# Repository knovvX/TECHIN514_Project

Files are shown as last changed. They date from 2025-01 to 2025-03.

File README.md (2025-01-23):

# TECHIN514_Project

`Diyun Lu 2430741`

### Sonic Flow - A Music Visualization Device

#### Overview

Sonic Flow senses the music around and visualize the waveform. The sensing device is responsible for detecting the music around. And the display device will display the corresponding waveforms together with a part acting as a monotrome to display the bpm.

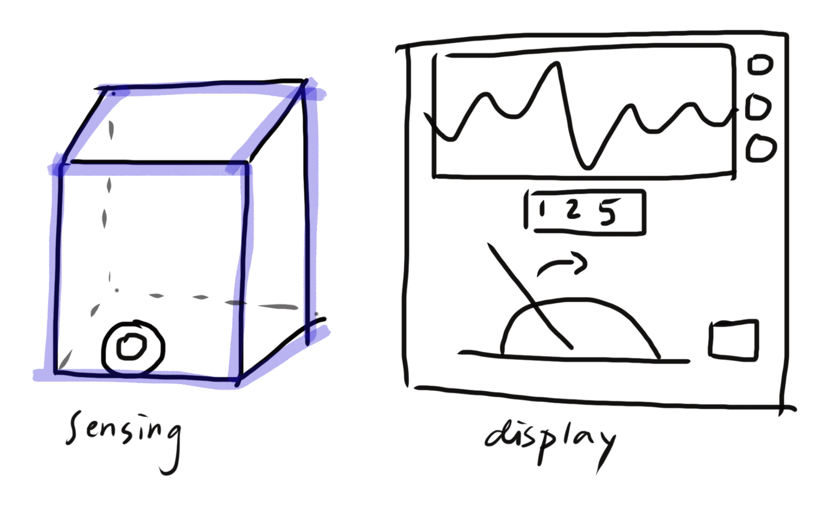
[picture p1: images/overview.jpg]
 

#### Sensing Device

The sensing device is equipped with a microphone sensor, which is recording the sound waves and send it to display device. A bluetooth module of esp32 will handle this transmission, since in the application, these two devices should not be very far, so I chose bluetooth. Also the sound level will affect the brightness of the LED strip around the cube, louder the sound is, brighter the LED is.

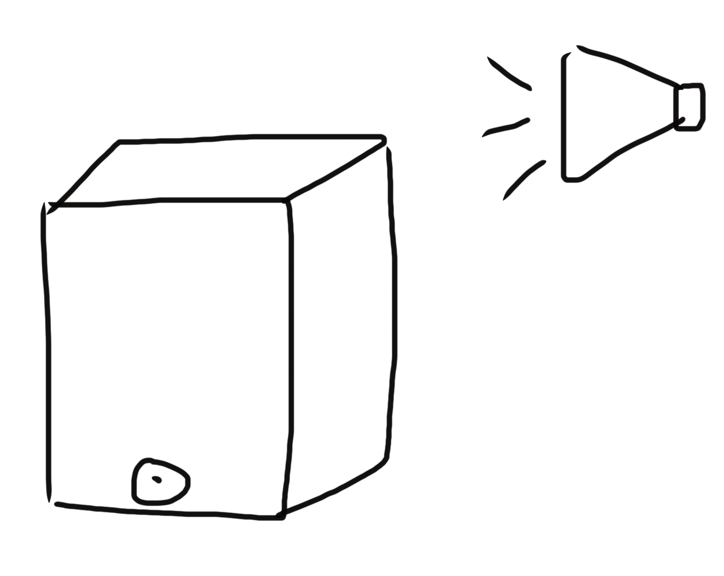
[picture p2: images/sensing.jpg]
sensing


#### Display Device

The display device is mainly displaying the waveform and the bpm of the music detected. BPM is displayed through the stepper-motor-driven gauge needle as a monotrome. Further ML will be embedded on the microncontroller to detect the emotion of the music and also display it on the OLED. A design of different kinds of waveforms will be enabled by a button to switch between different designs.

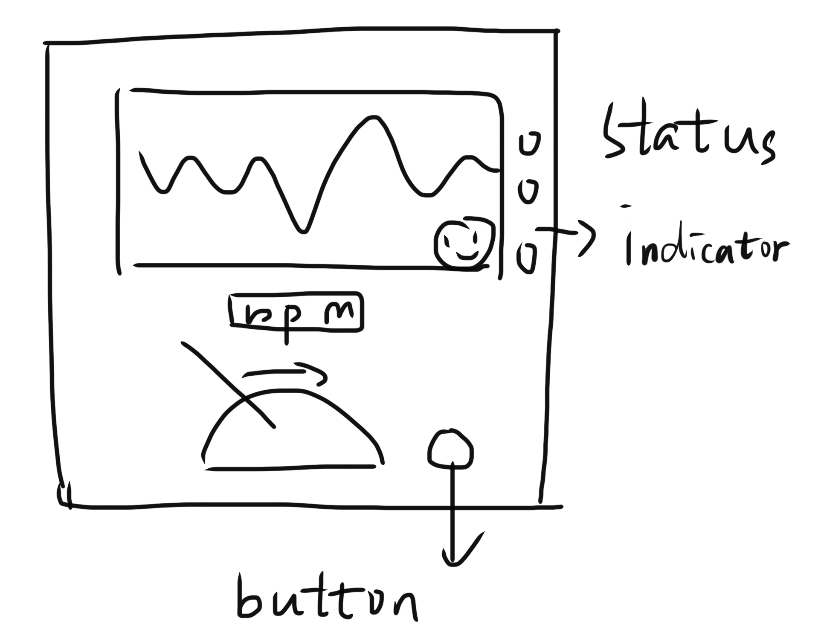
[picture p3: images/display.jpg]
display


#### Connection Diagram

The connection of the two parts are shown below. They connect with each other through ESP32's Bluetooth module. And ESP32 is responsible for the control of other sensors.

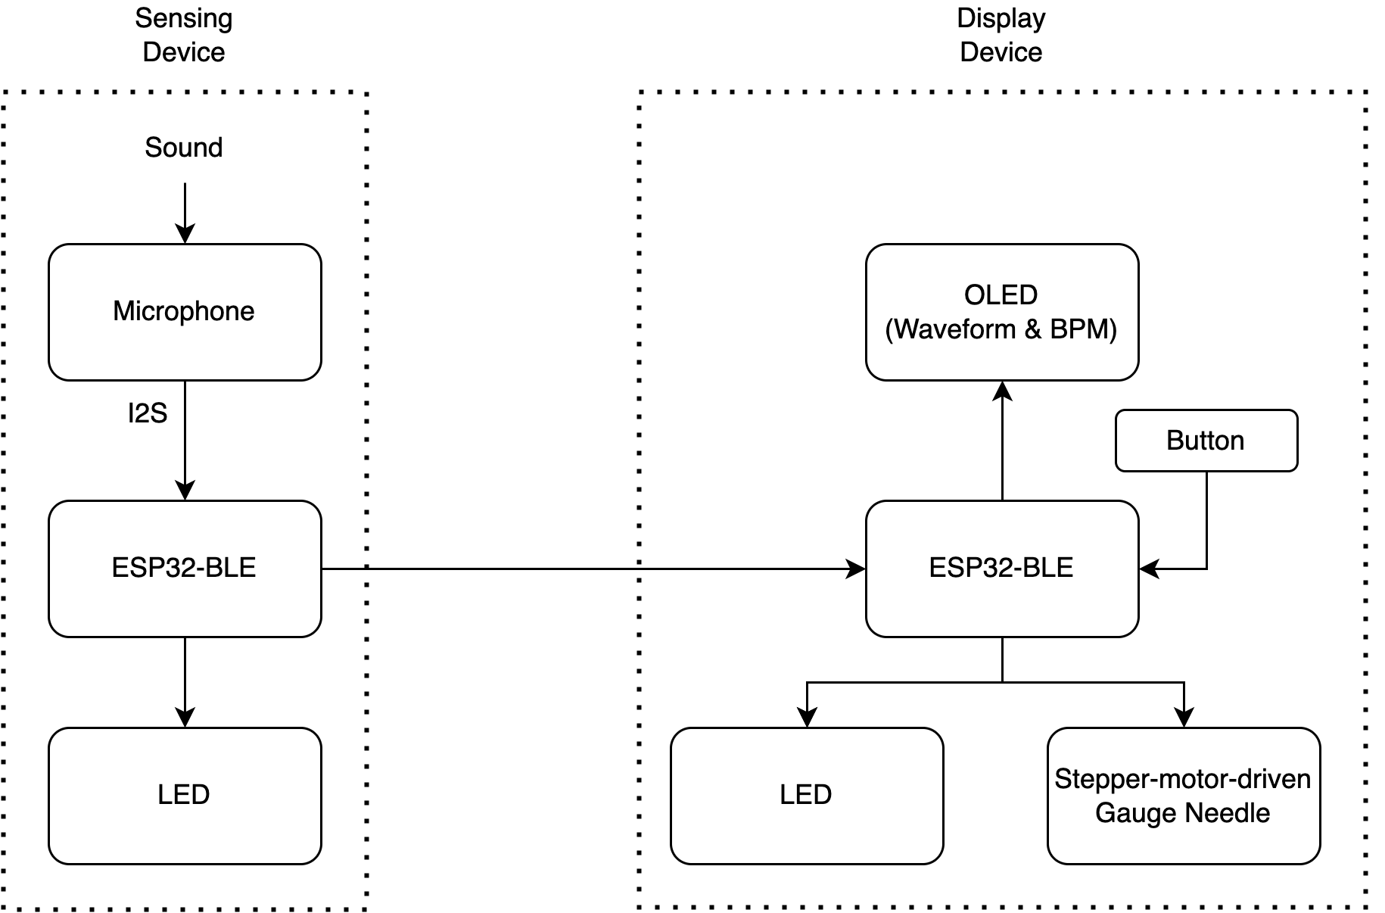
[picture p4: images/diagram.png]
diagram


#### Device Composition

| Device | Sensor / Element | Functionality |
| --- | --- | --- |
| Sensing | SPH0645LM4H-B | Microphone |
| Sensing | 3.7V / ++? | Battery |
| Display | 3.7V / ++? | Battery |
| Display | SSD1305(Long, for waves),https://www.adafruit.com/product/292,Adafruit OLED FeatherWing(Small, for displaying bpm) | OLED |
| Display | D6R90 F2 LFS | Button |
| Display/Sensing | RGB | LED |
| Display | https://www.adafruit.com/product/2424 | Stepper-motor-driven Gauge Needle |
| | ESP32 | Bluetooth and control |

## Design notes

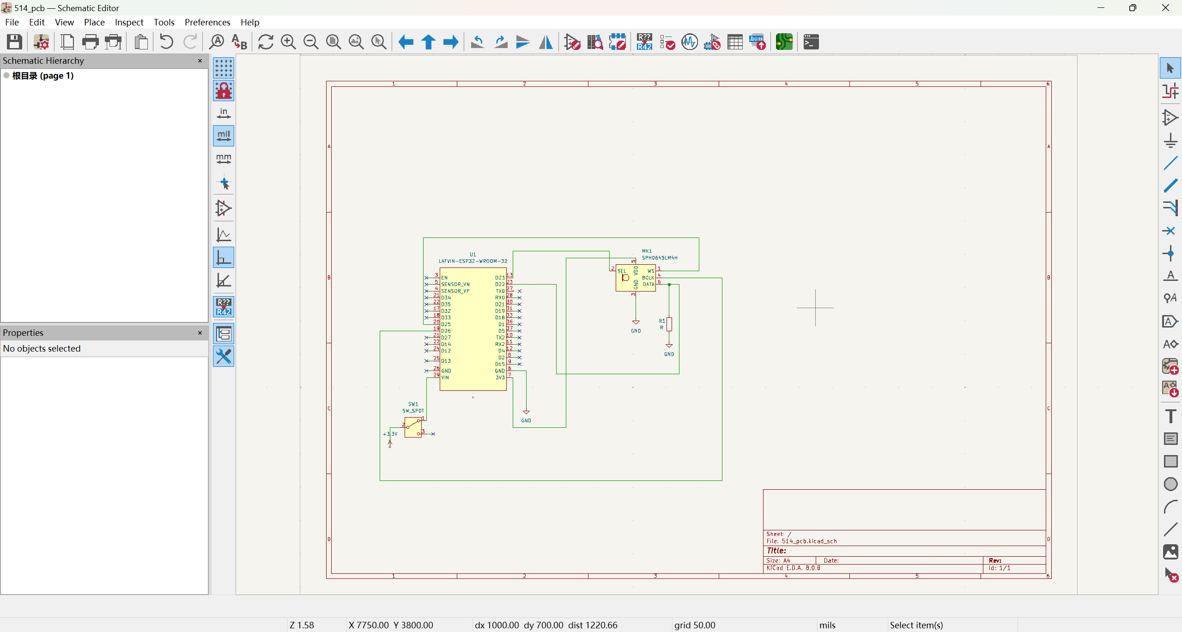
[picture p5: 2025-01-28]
pcb_schematic.png

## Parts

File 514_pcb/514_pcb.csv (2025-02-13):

Source: | /Users/diyunlu/Documents/GitHub/TECHIN514_Project/514_pcb/514_pcb.kicad_sch
Date: | 2025-02-12T16:00:10-0800
Tool: | Eeschema 8.0.8
Generator: | /Applications/KiCad/KiCad.app/Contents/SharedSupport/plugins/bom_csv_grouped_by_value.py
Component Count: | 5
Collated Components:
Item | Qty | Reference(s) | Value | LibPart | Footprint | Datasheet | DNP | Datasheet | Description | Footprint
1 | 1 | BT1 | Battery_Cell | Device:Battery_Cell | Connector_JST:JST_NV_B02P-NV_1x02_P5.00mm_Vertical | ~ |  | ~ | Single-cell battery | Connector_JST:JST_NV_B02P-NV_1x02_P5.00mm_Vertical
2 | 1 | MK1 | SPH0645LM4H | Sensor_Audio:SPH0645LM4H | Sensor_Audio:Knowles_SPH0645LM4H-6_3.5x2.65mm | https://www.knowles.com/docs/default-source/default-document-library/sph0645lm4h-1-datasheet.pdf |  | https://www.knowles.com/docs/default-source/default-document-library/sph0645lm4h-1-datasheet.pdf | Knowles MEMS Microphone, 24-bit I2S, 65 dBA SNR, LGA-6 | Sensor_Audio:Knowles_SPH0645LM4H-6_3.5x2.65mm
3 | 1 | R1 | R = 10k | Device:R | Resistor_SMD:R_0603_1608Metric_Pad0.98x0.95mm_HandSolder | ~ |  | ~ | Resistor | Resistor_SMD:R_0603_1608Metric_Pad0.98x0.95mm_HandSolder
4 | 1 | SW1 | SW_SPDT | Switch:SW_SPDT | Button_Switch_SMD:SW_SPDT_PCM12 | ~ |  | ~ | Switch, single pole double throw | Button_Switch_SMD:SW_SPDT_PCM12
5 | 1 | U1 | ~ | SeeedXiao:XIAO_ESP32_SENSE | SeeedXiao:XIAO_ESP32_SENSE |  |  |  |  | SeeedXiao:XIAO_ESP32_SENSE

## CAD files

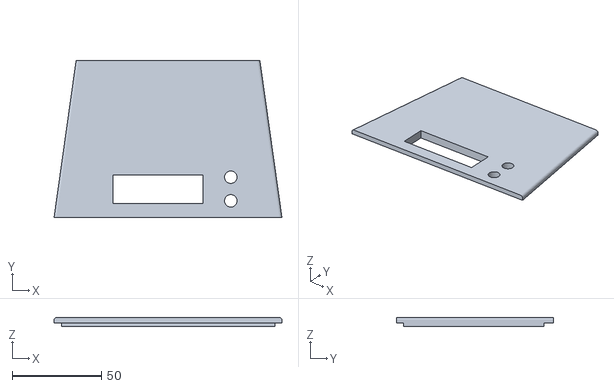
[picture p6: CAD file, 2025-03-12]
514_display/test 3d print/514_display v7upbpt.stl
128.0 x 88.4 x 5.02

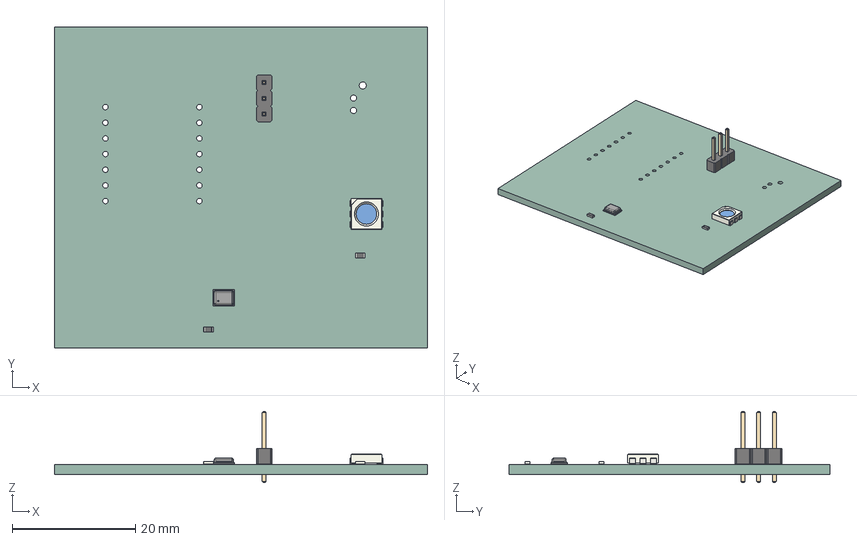
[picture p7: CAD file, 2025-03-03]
514_pcb/514_pcb.step
60.5 x 52.0 x 11.5 mm
R_0603_1608Metric x 2
PinHeader_1x03_P254mm_Vertical
LED_RGB_5050_6
Knowles_SPH0645LM4H-6_3.5x2.65mm
514_pcb_PCB

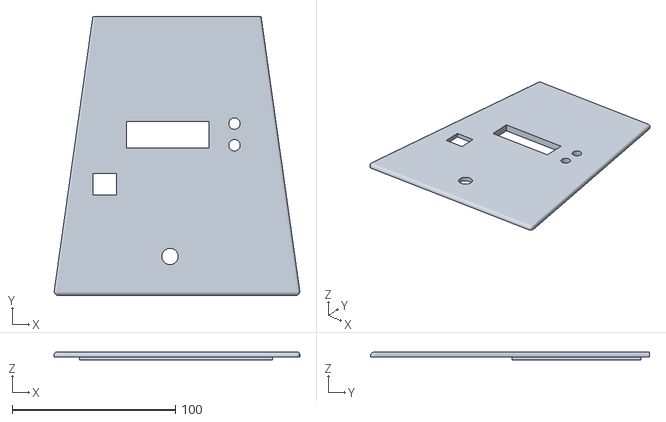
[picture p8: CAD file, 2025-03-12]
514_display/514_display v9lid.stl
150.5 x 170.9 x 5.05

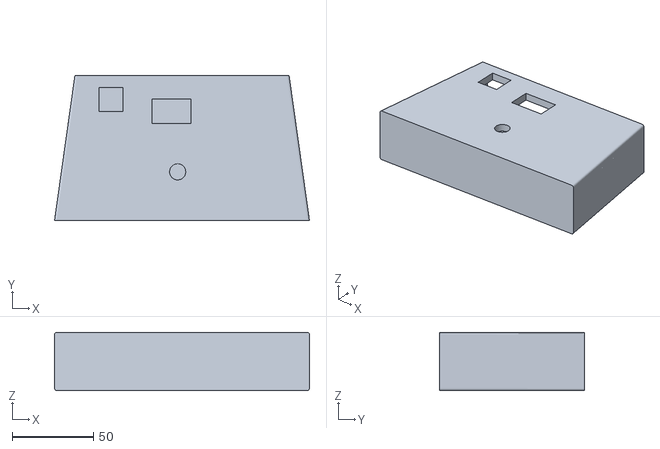
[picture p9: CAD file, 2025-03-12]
514_display/test 3d print/514_display v2botbig.stl
157.4 x 89.6 x 36.1

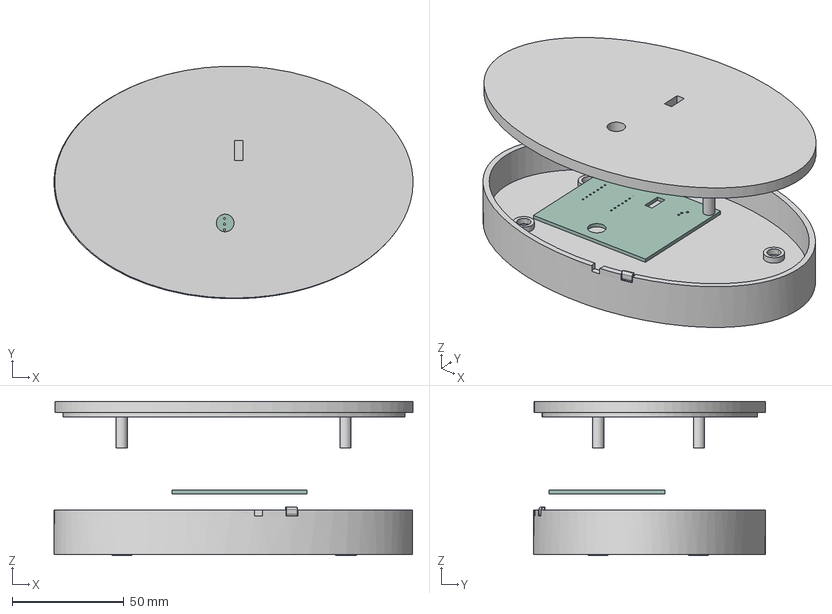
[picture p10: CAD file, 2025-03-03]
514_pcb/514_pcb_sensing_enclosure v12.step
160.5 x 103.9 x 69.1 mm
514_pcb_PCB

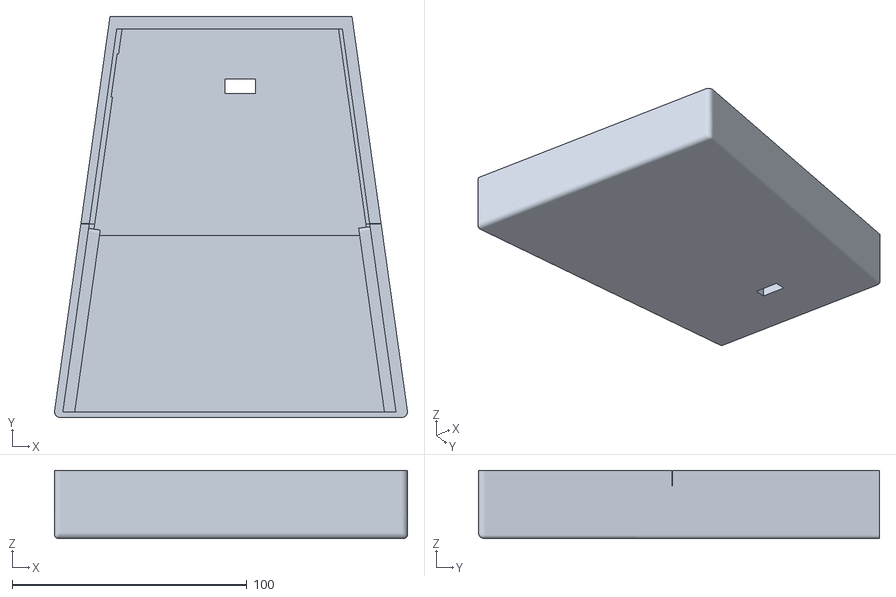
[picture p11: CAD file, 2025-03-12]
514_display/514_display v9.stl
150.4 x 171.0 x 29.0

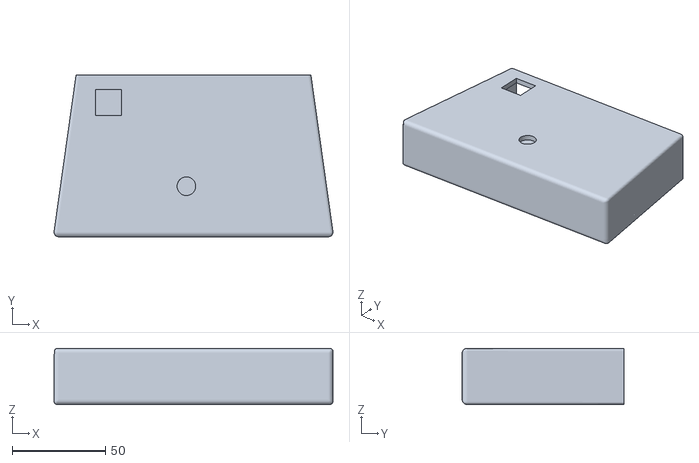
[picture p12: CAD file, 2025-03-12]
514_display/test 3d print/514_display v3_bot.stl
149.5 x 86.6 x 30.1

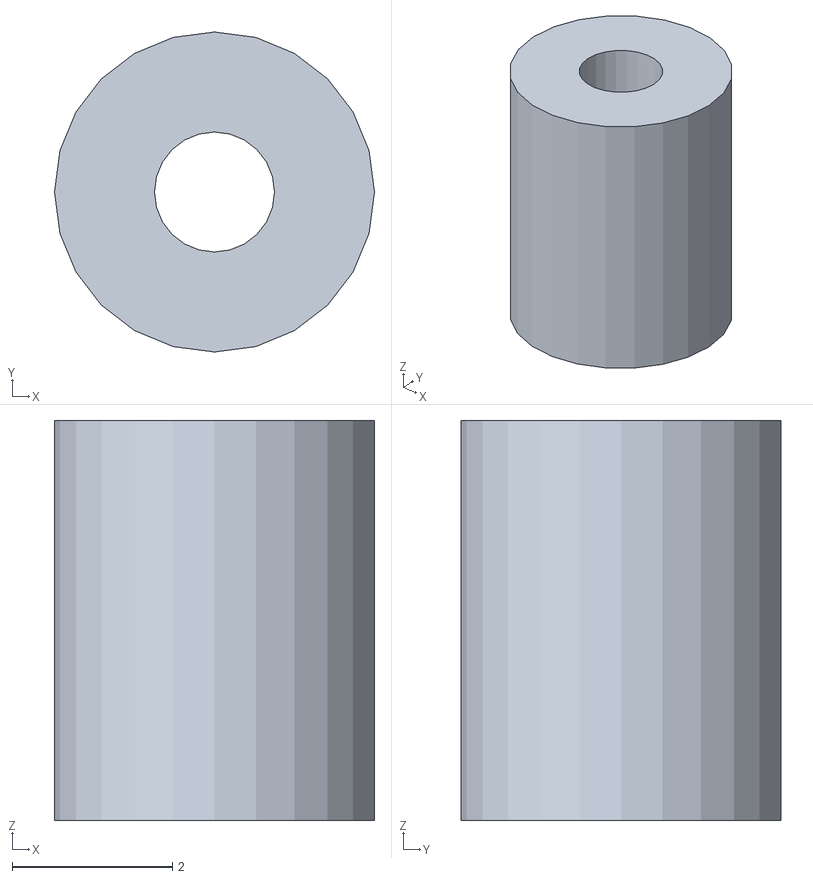
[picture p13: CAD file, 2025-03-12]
514_display/needle bot.stl
4.00 x 4.00 x 5.00

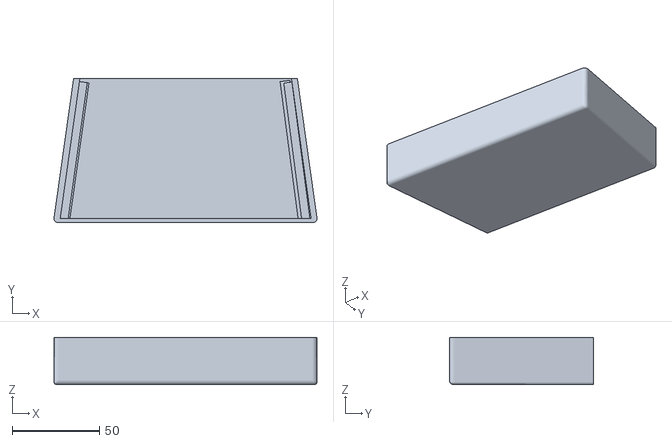
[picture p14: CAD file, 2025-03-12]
514_display/test 3d print/514_display v7botbot.stl
150.4 x 82.6 x 27.0

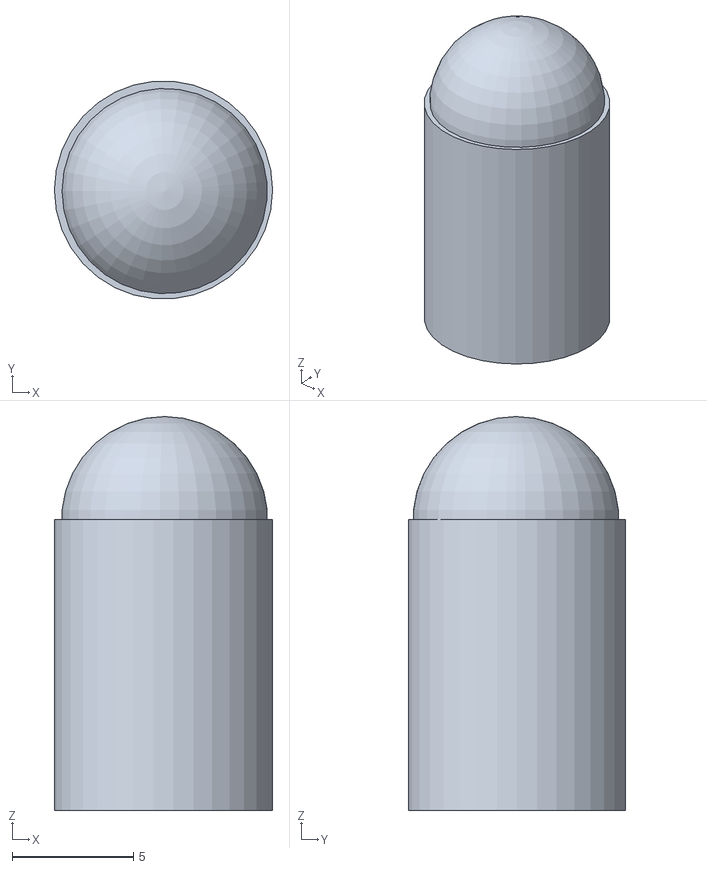
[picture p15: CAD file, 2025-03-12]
514_display/needle mid.stl
9.00 x 8.96 x 16.2

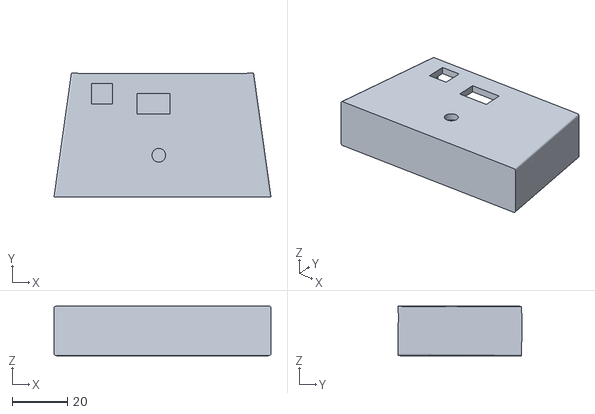
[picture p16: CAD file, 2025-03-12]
514_display/test 3d print/ldy_test_down.stl
78.7 x 44.8 x 18.0

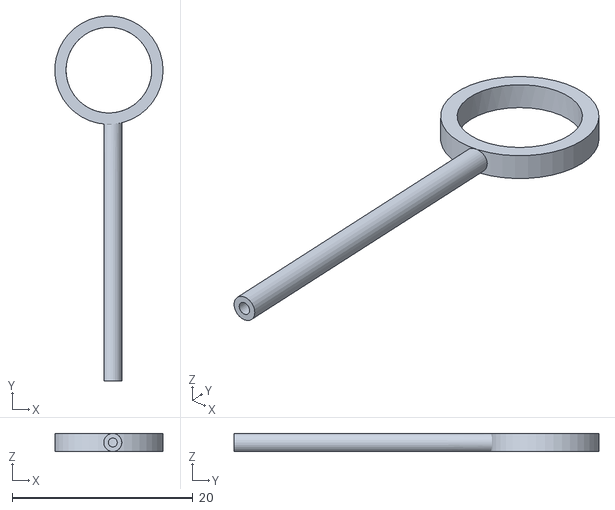
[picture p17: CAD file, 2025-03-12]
514_display/needle up.stl
12.0 x 40.4 x 2.00

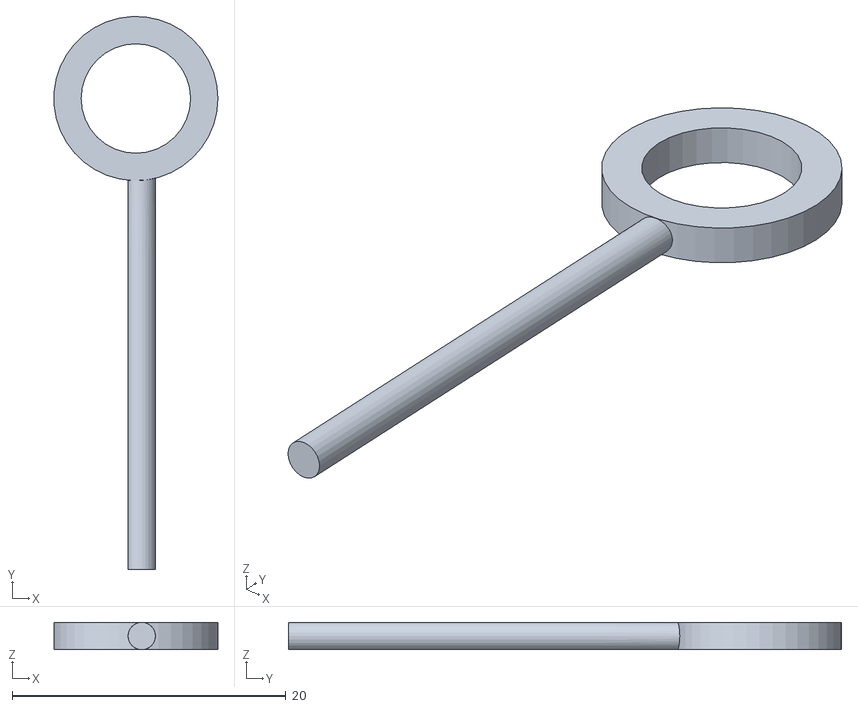
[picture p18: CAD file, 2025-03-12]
514_display/test 3d print/514_display v7need2.stl
12.0 x 40.4 x 2.00

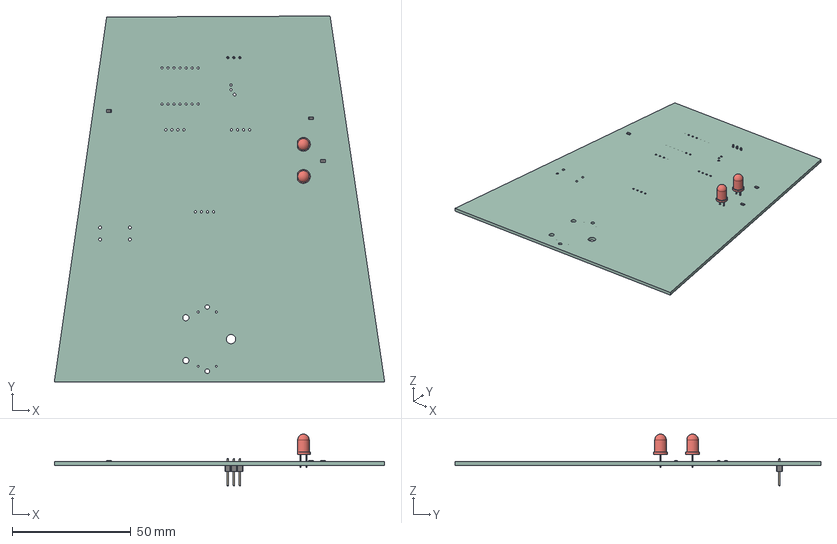
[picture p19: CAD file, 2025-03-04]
514_display/514_display.step
139.0 x 154.0 x 21.8 mm
LED_D5.0mm x 2
R_0805_2012Metric x 3
PinHeader_1x03_P254mm_Vertical
514_display_PCB

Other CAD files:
514_display/test 3d print/514_display v7upup.stl
514_display/test 3d print/514_display v5 bot.stl
514_display/test 3d print/514_display v7need1.stl
514_display/test 3d print/514_display v5 up1.stl
514_display/514_display v8.stl
514_display/test 3d print/514_display upup.stl
514_display/test 3d print/514_display v1.stl
514_display/test 3d print/514_display v2 upbot.stl
514_display/test 3d print/514_display v5up2.stl
514_display/test 3d print/514_display v7botup.stl
514_display/test 3d print/514_display_down.stl
514_display/test 3d print/ldy_test_up1.stl
514_display/test 3d print/ldy_test_up2.stl

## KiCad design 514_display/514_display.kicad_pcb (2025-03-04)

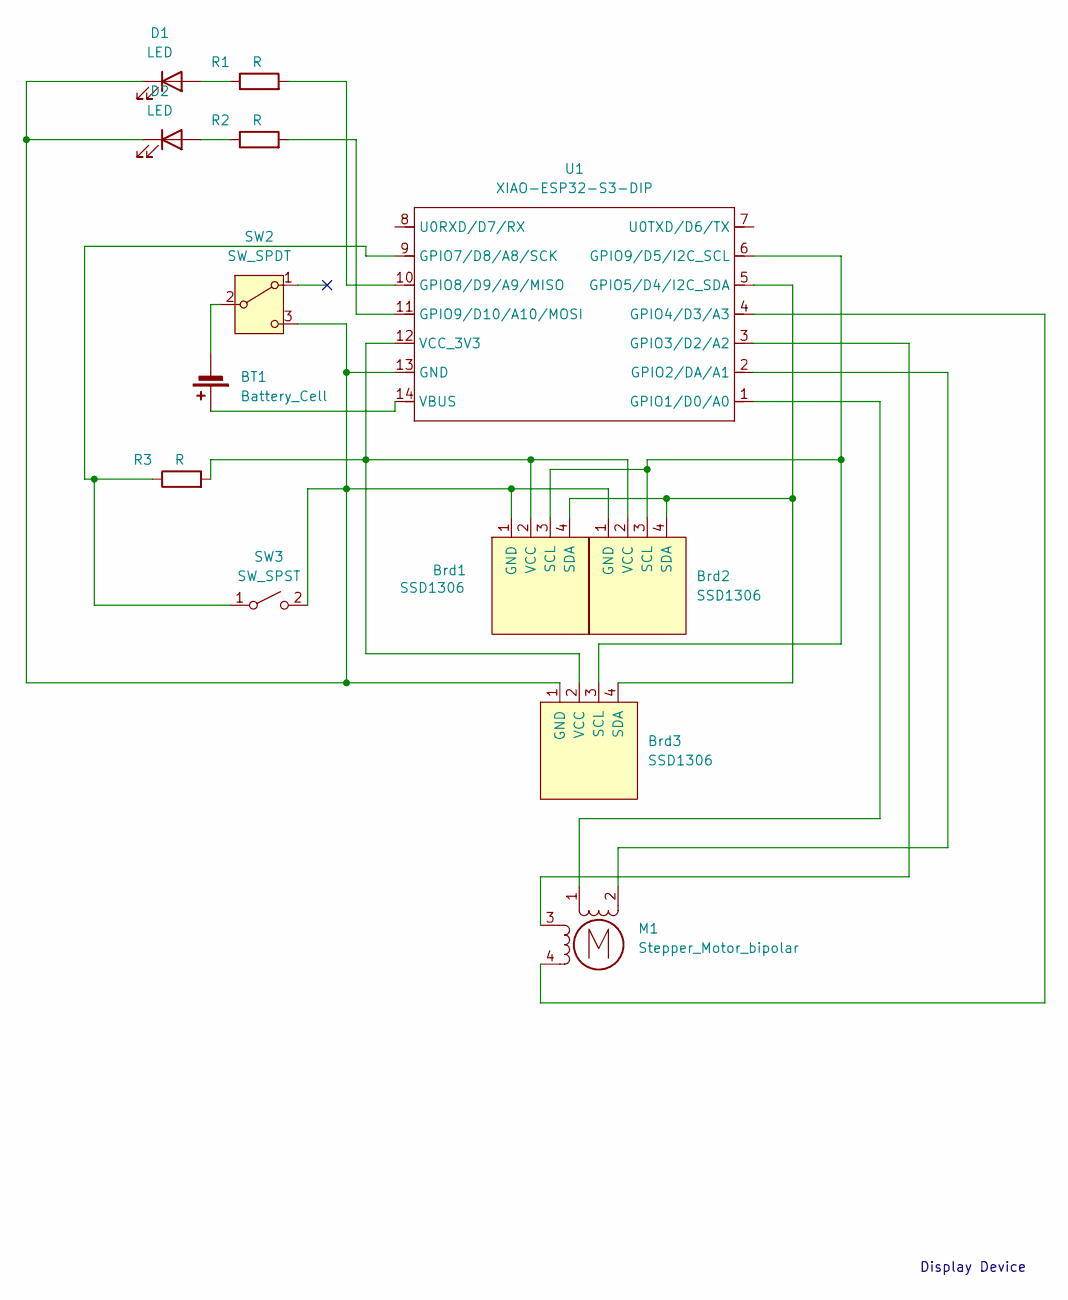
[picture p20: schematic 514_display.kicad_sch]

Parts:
BT1: Battery_Cell; JST_JWPF_B02B-JWPF-SK-R_1x02_P2.00mm_Vertical
Brd1, Brd2, Brd3: SSD1306; 128x64OLED
D1, D2: LED; LED_D5.0mm
M1: Stepper_Motor_bipolar; x27_stepper_two_holes
R1, R2, R3: R; R_0805_2012Metric_Pad1.20x1.40mm_HandSolder
SW2: SW_SPDT; PinHeader_1x03_P2.54mm_Vertical
SW3: SW_SPST; SW_PUSH-12mm
U1: XIAO-ESP32-S3-DIP; XIAO-ESP32S3-DIP

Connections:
unnamed: BT1.1 (+), U1.14 (VBUS)
unnamed: BT1.2 (-), SW2.2 (B)
unnamed: Brd1.1 (GND), Brd2.1 (GND), Brd3.1 (GND), D1.1 (K), D2.1 (K), SW2.3 (C), SW3.2 (B), U1.13 (GND)
unnamed: Brd1.3 (SCL), Brd2.3 (SCL), Brd3.3 (SCL), U1.6 (GPIO9/D5/I2C_SCL)
unnamed: Brd1.4 (SDA), Brd2.4 (SDA), Brd3.4 (SDA), U1.5 (GPIO5/D4/I2C_SDA)
unnamed: Brd1.2 (VCC), Brd2.2 (VCC), Brd3.2 (VCC), R3.2, U1.12 (VCC_3V3)
unnamed: D1.2 (A), R1.1
unnamed: D2.2 (A), R2.1
unnamed: M1.2 (-), U1.2 (GPIO2/DA/A1)
unnamed: R3.1, SW3.1 (A), U1.9 (GPIO7/D8/A8/SCK)
unnamed: M1.1, U1.1 (GPIO1/D0/A0)
unnamed: M1.3, U1.3 (GPIO3/D2/A2)
unnamed: M1.4, U1.4 (GPIO4/D3/A3)
unnamed: R1.2, U1.10 (GPIO8/D9/A9/MISO)
unnamed: R2.2, U1.11 (GPIO9/D10/A10/MOSI)

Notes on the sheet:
Display Device

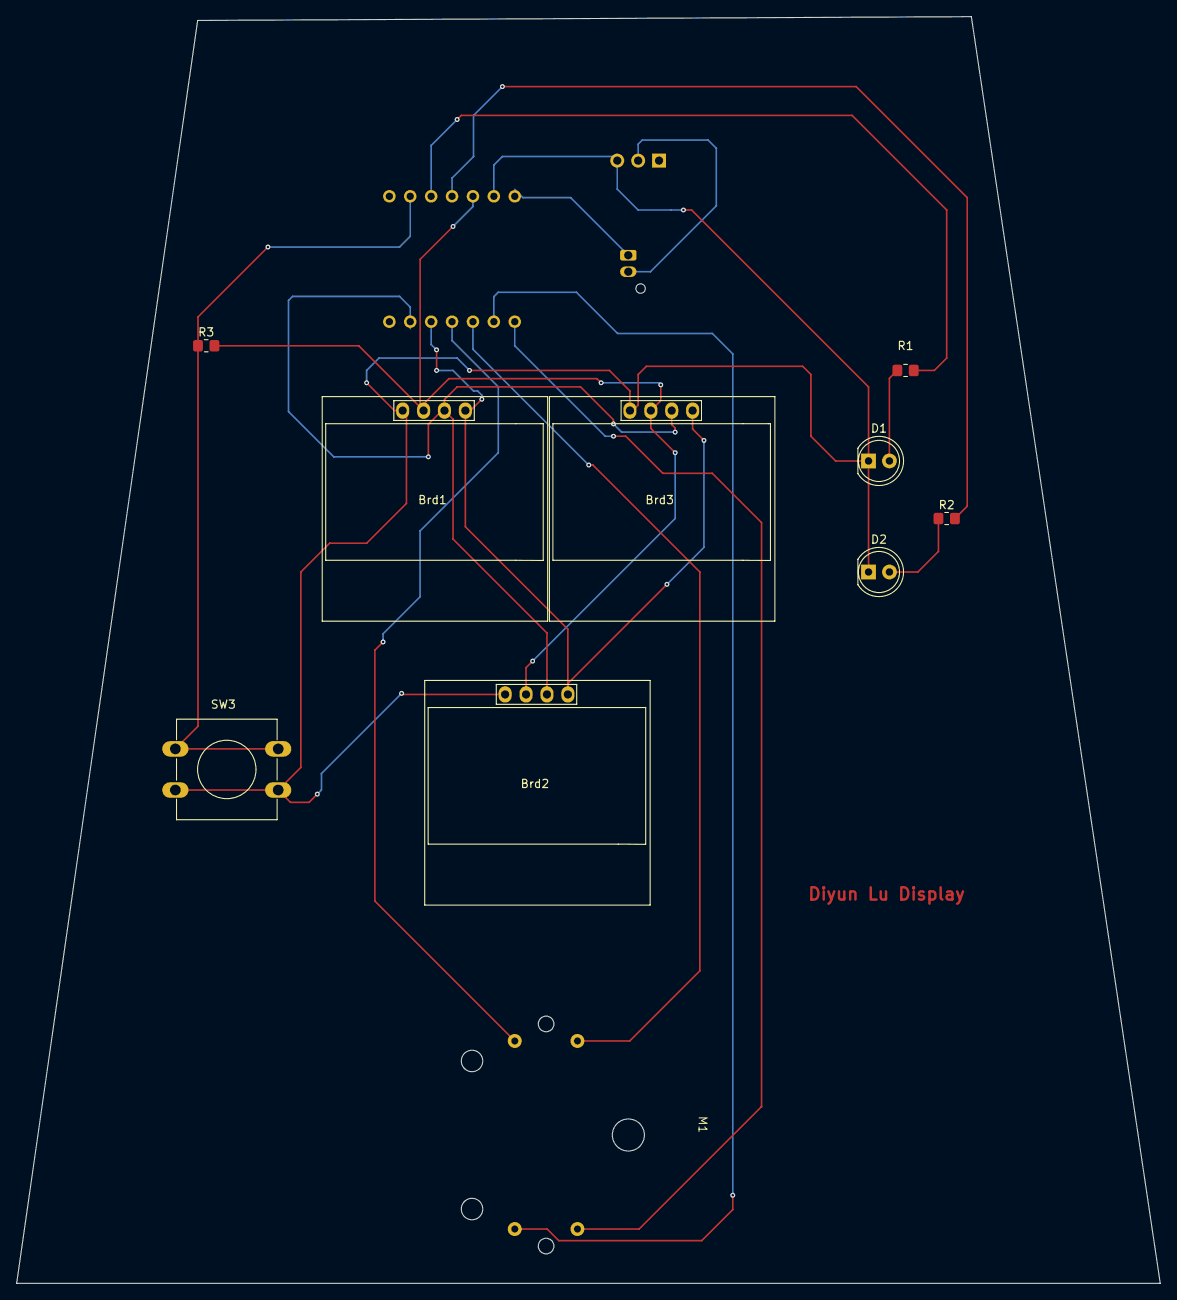
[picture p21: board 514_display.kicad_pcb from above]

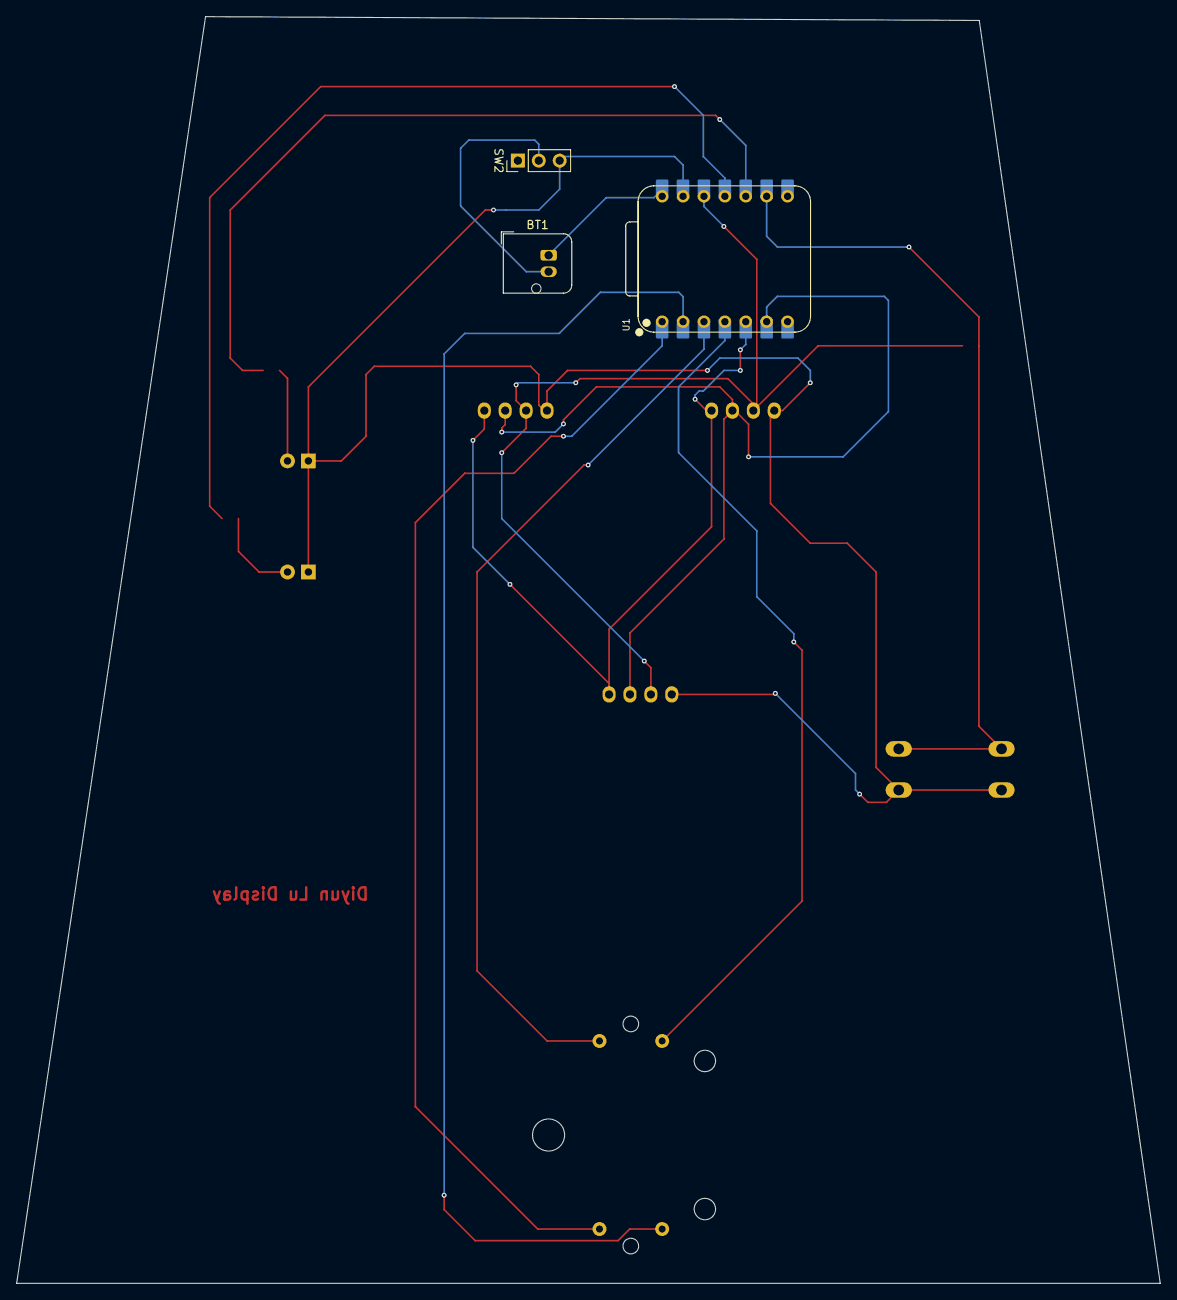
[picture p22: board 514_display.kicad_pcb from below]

Board: 2 copper layers, 139.0 x 154.0 mm, 13 parts (3 on the bottom side), 15 nets.

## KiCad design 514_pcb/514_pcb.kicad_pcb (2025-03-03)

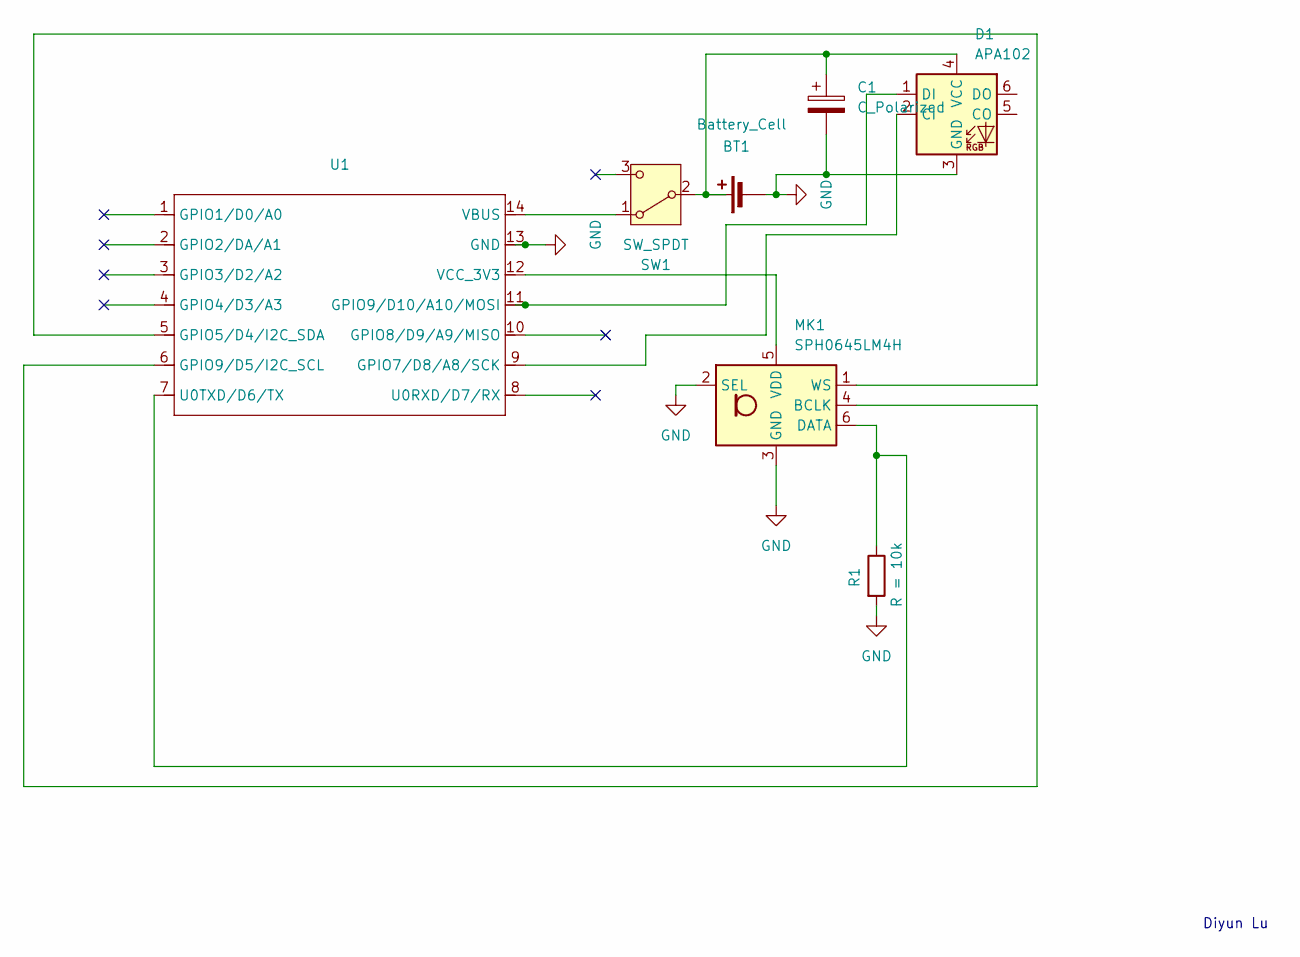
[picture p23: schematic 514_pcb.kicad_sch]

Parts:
BT1: Battery_Cell; JST_JWPF_B02B-JWPF-SK-R_1x02_P2.00mm_Vertical
C1: C_Polarized; R_0603_1608Metric_Pad0.98x0.95mm_HandSolder
D1: APA102; LED_RGB_5050-6
MK1: SPH0645LM4H; Knowles_SPH0645LM4H-6_3.5x2.65mm
R1: R = 10k; R_0603_1608Metric_Pad0.98x0.95mm_HandSolder
SW1: SW_SPDT; PinHeader_1x03_P2.54mm_Vertical
U1: XIAO-ESP32S3-DIP

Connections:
GND: BT1.2 (-), C1.2, D1.3 (GND), MK1.2 (SEL), MK1.3 (GND), R1.2, U1.13 (GND)
unnamed: BT1.1 (+), C1.1, D1.4 (VCC), SW1.2 (B)
unnamed: D1.2 (CI), U1.9 (GPIO7/D8/A8/SCK)
unnamed: D1.1 (DI), U1.11 (GPIO9/D10/A10/MOSI)
unnamed: MK1.4 (BCLK), U1.6 (GPIO9/D5/I2C_SCL)
unnamed: MK1.6 (DATA), R1.1, U1.7 (U0TXD/D6/TX)
unnamed: MK1.5 (VDD), U1.12 (VCC_3V3)
unnamed: MK1.1 (WS), U1.5 (GPIO5/D4/I2C_SDA)
unnamed: SW1.1 (A), U1.14 (VBUS)

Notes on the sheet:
Diyun Lu

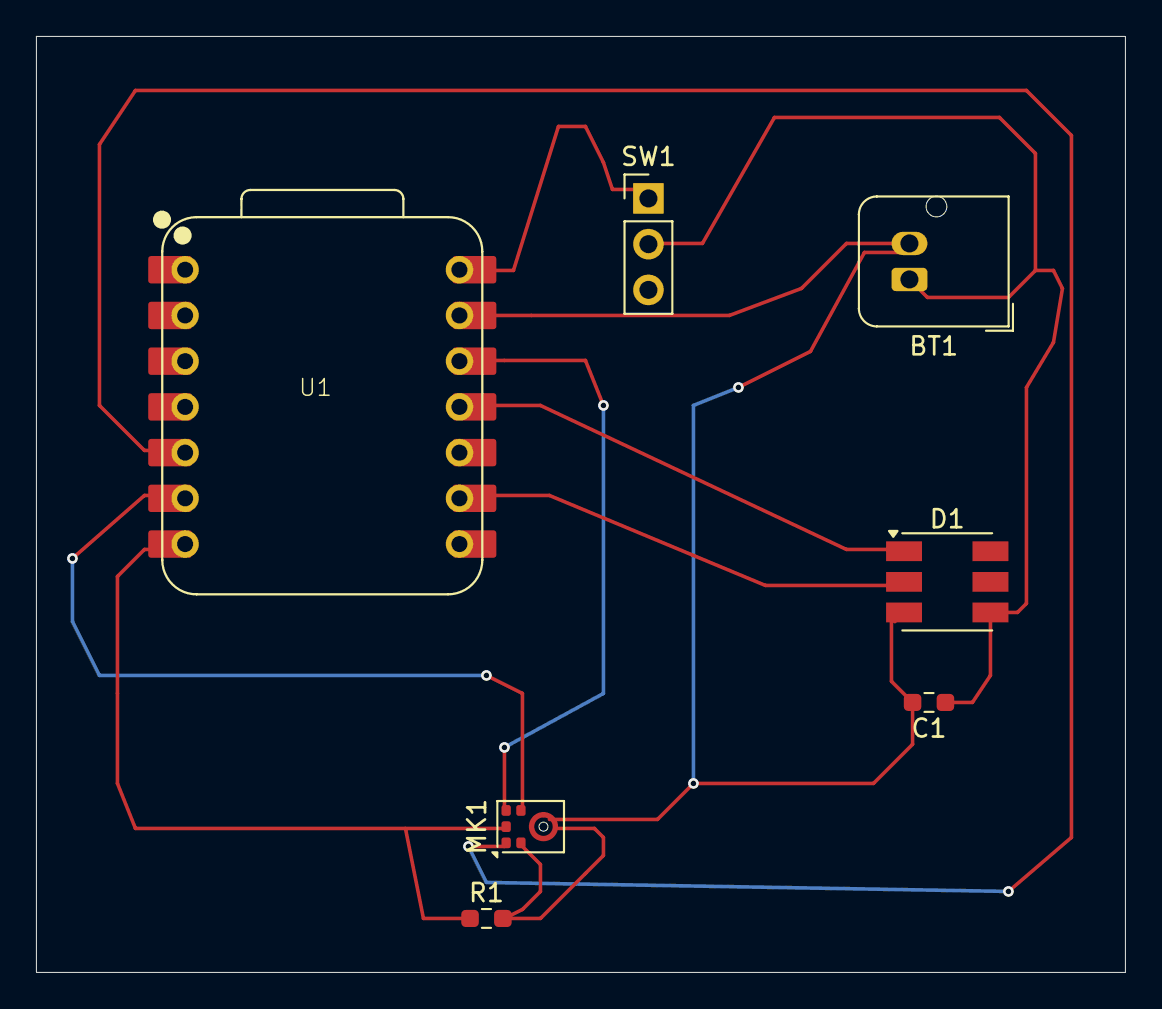
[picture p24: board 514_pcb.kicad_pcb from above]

Board: 2 copper layers, 60.5 x 52.0 mm, 7 parts (0 on the bottom side), 9 nets.

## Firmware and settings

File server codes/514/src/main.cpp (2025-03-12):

// #include <ESP_I2S.h>
// #include <BLEDevice.h>
// #include <BLEServer.h>
// #include <BLEUtils.h>
// #include <BLE2902.h>
// #include <Arduino.h>
// #include <math.h>

// // I2S settings
// I2SClass I2S;
// #define SAMPLE_RATE 16000
// #define PDM_DATA_PIN 41
// #define PDM_CLOCK_PIN 42

// // Buffer settings
// #define BUFFER_SIZE 512  // Larger buffer for better frequency analysis
// int16_t sampleBuffer[BUFFER_SIZE];
// int16_t processedBuffer[BUFFER_SIZE]; // Buffer for processed samples
// int bufferIndex = 0;

// // BLE server and characteristic definitions
// BLEServer *pServer = NULL;
// BLECharacteristic *pCharacteristic = NULL;
// bool deviceConnected = false;
// bool oldDeviceConnected = false;

// // Define UUIDs for the service and characteristic
// #define SERVICE_UUID "0cebcba9-4624-4999-9cec-5debf01d8ecb"
// #define CHARACTERISTIC_UUID "65f04fbf-01ac-4954-a999-af6b77c65fdf"

// // Beat detection parameters
// #define ENERGY_SMOOTHING 0.2      // Smoothing factor for energy calculation
// #define BEAT_THRESHOLD 1.5        // Energy must be this times the average to trigger a beat
// #define MIN_BEAT_INTERVAL 250     // Minimum time between beats (ms)
// #define BEAT_HOLD_TIME 100        // Hold the beat indicator for this long (ms)

// // Energy buffer for beat detection
// #define ENERGY_BUFFER_SIZE 32
// float energyBuffer[ENERGY_BUFFER_SIZE];
// int energyIndex = 0;
// float currentEnergy = 0;
// float averageEnergy = 0;
// bool beatDetected = false;
// unsigned long lastBeatTime = 0;
// unsigned long beatIndicatorTime = 0;
// float beatStrength = 0.0;

// // Noise reduction parameters
// #define NOISE_FLOOR 300            // Initial noise floor estimate
// #define NOISE_ADAPT_RATE 0.01      // Rate to adapt noise floor estimate
// float noiseFloor = NOISE_FLOOR;

// // Response variables to BLE requests
// #define MESSAGE_SIZE 20
// uint8_t messageData[MESSAGE_SIZE]; // Data to send over BLE

// // Server callbacks class to detect connection status
// class MyServerCallbacks: public BLEServerCallbacks {
//     void onConnect(BLEServer* pServer) {
//       deviceConnected = true;
//       Serial.println("Device connected");
//     }

//     void onDisconnect(BLEServer* pServer) {
//       deviceConnected = false;
//       Serial.println("Device disconnected");
//     }
// };

// // Remove DC offset and reduce noise
// void applyNoiseReduction(int16_t* samples, int16_t* output, int numSamples) {
//   // Calculate the average (DC offset)
//   int32_t sum = 0;
//   for (int i = 0; i < numSamples; i++) {
//     sum += samples[i];
//   }
//   int16_t dcOffset = sum / numSamples;
  
//   // Apply DC offset removal and noise gate
//   for (int i = 0; i < numSamples; i++) {
//     // Remove DC offset
//     output[i] = samples[i] - dcOffset;
    
//     // Apply noise gate
//     if (abs(output[i]) < noiseFloor) {
//       output[i] = 0;
//     }
//   }
  
//   // Update noise floor estimate (adapt to environment)
//   int16_t currentNoiseLevel = 0;
//   for (int i = 0; i < numSamples; i++) {
//     currentNoiseLevel += abs(output[i]);
//   }
//   currentNoiseLevel /= numSamples;
  
//   // Only adapt noise floor during quiet periods
//   if (currentNoiseLevel < noiseFloor * 2) {
//     noiseFloor = (1 - NOISE_ADAPT_RATE) * noiseFloor + NOISE_ADAPT_RATE * currentNoiseLevel;
//   }
// }

// // Detect beats using energy-based algorithm
// bool detectBeat(int16_t* samples, int numSamples) {
//   // Calculate signal energy (RMS)
//   float energy = 0;
//   for (int i = 0; i < numSamples; i++) {
//     energy += (float)samples[i] * samples[i];
//   }
//   energy = sqrt(energy / numSamples);
  
//   // Smooth the energy value
//   currentEnergy = (1 - ENERGY_SMOOTHING) * currentEnergy + ENERGY_SMOOTHING * energy;
  
//   // Store in circular buffer
//   energyBuffer[energyIndex] = currentEnergy;
//   energyIndex = (energyIndex + 1) % ENERGY_BUFFER_SIZE;
  
//   // Calculate average energy
//   float sum = 0;
//   for (int i = 0; i < ENERGY_BUFFER_SIZE; i++) {
//     sum += energyBuffer[i];
//   }
//   averageEnergy = sum / ENERGY_BUFFER_SIZE;
  
//   // Check if enough time has passed since the last beat
//   unsigned long currentTime = millis();
//   if (currentTime - lastBeatTime < MIN_BEAT_INTERVAL) {
//     return false;
//   }
  
//   // Beat detection logic
//   if (currentEnergy > averageEnergy * BEAT_THRESHOLD && currentEnergy > noiseFloor * 3) {
//     lastBeatTime = currentTime;
//     beatIndicatorTime = currentTime;
    
//     // Calculate beat strength (normalized)
//     beatStrength = constrain((currentEnergy - averageEnergy) / averageEnergy, 0.0, 1.0);
    
//     return true;
//   }
  
//   return false;
// }

// // Send beat data to client
// void sendBeatData(float strength) {
//   if (!deviceConnected) return;
  
//   // Create a structured message: [flag byte, strength float (4 bytes)]
//   messageData[0] = 0x01; // Beat indicator flag
  
//   // Convert float to bytes
//   memcpy(&messageData[1], &strength, sizeof(float));
  
//   // Send the data
//   pCharacteristic->setValue(messageData, 5); // 1 flag byte + 4 bytes float
//   pCharacteristic->notify();
  
//   Serial.print("Beat detected! Strength: ");
//   Serial.println(strength);
// }

// void setup() {
//   // Initialize serial
//   Serial.begin(115200);
//   while (!Serial) {
//     ; // wait for serial port to connect
//   }
//   Serial.println("ESP32 PDM Beat Detection Server");

//   // Setup I2S for PDM microphone
//   I2S.setPinsPdmRx(PDM_CLOCK_PIN, PDM_DATA_PIN);
  
//   if (!I2S.begin(I2S_MODE_PDM_RX, SAMPLE_RATE, I2S_DATA_BIT_WIDTH_16BIT, I2S_SLOT_MODE_MONO)) {
//     Serial.println("Failed to initialize I2S!");
//     while (1); // do nothing
//   }
  
//   Serial.println("I2S PDM initialized");
  
//   // Initialize energy buffer
//   for (int i = 0; i < ENERGY_BUFFER_SIZE; i++) {
//     energyBuffer[i] = 0.0;
//   }
  
//   // Initialize message data
//   memset(messageData, 0, MESSAGE_SIZE);
  
//   // Initialize BLE
//   BLEDevice::init("ESP32_Beat_Server");
  
//   // Create the BLE Server
//   pServer = BLEDevice::createServer();
//   pServer->setCallbacks(new MyServerCallbacks());
  
//   // Create the BLE Service
//   BLEService *pService = pServer->createService(SERVICE_UUID);
  
//   // Create a BLE Characteristic
//   pCharacteristic = pService->createCharacteristic(
//                       CHARACTERISTIC_UUID,
//                       BLECharacteristic::PROPERTY_READ   |
//                       BLECharacteristic::PROPERTY_WRITE  |
//                       BLECharacteristic::PROPERTY_NOTIFY |
//                       BLECharacteristic::PROPERTY_INDICATE
//                     );
  
//   // Create a BLE Descriptor
//   pCharacteristic->addDescriptor(new BLE2902());
  
//   // Start the service
//   pService->start();
  
//   // Start advertising
//   BLEAdvertising *pAdvertising = BLEDevice::getAdvertising();
//   pAdvertising->addServiceUUID(SERVICE_UUID);
//   pAdvertising->setScanResponse(true);
//   pAdvertising->setMinPreferred(0x06);
//   pAdvertising->setMinPreferred(0x12);
//   BLEDevice::startAdvertising();
  
//   Serial.println("BLE server ready, waiting for connections...");
// }

// void loop() {
//   // Read samples from I2S
//   int sample = I2S.read();
  
//   if (sample && sample != -1 && sample != 1) {
//     // Add sample to buffer
//     sampleBuffer[bufferIndex++] = (int16_t)sample;
    
//     // When buffer is full, process it
//     if (bufferIndex >= BUFFER_SIZE) {
//       // Apply noise reduction
//       applyNoiseReduction(sampleBuffer, processedBuffer, BUFFER_SIZE);
      
//       // Detect beats
//       beatDetected = detectBeat(processedBuffer, BUFFER_SIZE);
      
//       if (beatDetected && deviceConnected) {
//         // Send beat data to client
//         sendBeatData(beatStrength);
//       }
      
//       // If connected, optionally send a downsampled version of the audio
//       if (deviceConnected) {
//         // Send compressed representation of the signal
//         // This reduces the BLE data rate while still providing information about the signal
        
//         // Send just 10 representative samples (every 50th sample)
//         for (int i = 0; i < 10; i++) {
//           int idx = i * 50;
//           if (idx < BUFFER_SIZE) {
//             int16_t value = processedBuffer[idx];
//             pCharacteristic->setValue((uint8_t*)&value, sizeof(int16_t));
//             pCharacteristic->notify();
//             delay(5); // Small delay to avoid overwhelming the BLE stack
//           }
//         }
//       }
      
//       // Reset buffer index
//       bufferIndex = 0;
//     }
//   }
  
//   // Handle BLE connection status changes
//   if (!deviceConnected && oldDeviceConnected) {
//     delay(500); // Give the bluetooth stack time to get ready
//     pServer->startAdvertising(); // Restart advertising
//     Serial.println("Started advertising again");
//     oldDeviceConnected = deviceConnected;
//   }
  
//   if (deviceConnected && !oldDeviceConnected) {
//     oldDeviceConnected = deviceConnected;
//   }
// }

#include <ESP_I2S.h>
#include <BLEDevice.h>
#include <BLEServer.h>
#include <BLEUtils.h>
#include <BLE2902.h>
#include <Arduino.h>
#include <math.h>

// I2S settings
I2SClass I2S;
#define SAMPLE_RATE 16000
#define PDM_DATA_PIN 41
#define PDM_CLOCK_PIN 42

// Buffer settings
#define BUFFER_SIZE 512  // Larger buffer for better frequency analysis
int16_t sampleBuffer[BUFFER_SIZE];
int16_t processedBuffer[BUFFER_SIZE]; // Buffer for processed samples
int bufferIndex = 0;

// BLE server and characteristic definitions
BLEServer *pServer = NULL;
BLECharacteristic *pCharacteristic = NULL;
bool deviceConnected = false;
bool oldDeviceConnected = false;

// Define UUIDs for the service and characteristic
#define SERVICE_UUID "0cebcba9-4624-4999-9cec-5debf01d8ecb"
#define CHARACTERISTIC_UUID "65f04fbf-01ac-4954-a999-af6b77c65fdf"

// Beat detection parameters
#define ENERGY_SMOOTHING 0.3      // Smoothing factor for energy calculation
#define BEAT_THRESHOLD 1.1        // Energy must be this times the average to trigger a beat
#define MIN_BEAT_INTERVAL 200     // Minimum time between beats (ms)
#define BEAT_HOLD_TIME 100        // Hold the beat indicator for this long (ms)

// Energy buffer for beat detection
#define ENERGY_BUFFER_SIZE 32
float energyBuffer[ENERGY_BUFFER_SIZE];
int energyIndex = 0;
float currentEnergy = 0;
float averageEnergy = 0;
bool beatDetected = false;
unsigned long lastBeatTime = 0;
unsigned long beatIndicatorTime = 0;
float beatStrength = 0.0;

// Noise reduction parameters
#define NOISE_FLOOR 300            // Initial noise floor estimate
#define NOISE_ADAPT_RATE 0.01      // Rate to adapt noise floor estimate
float noiseFloor = NOISE_FLOOR;

// Response variables to BLE requests
#define MESSAGE_SIZE 20
uint8_t messageData[MESSAGE_SIZE]; // Data to send over BLE

// Server callbacks class to detect connection status
class MyServerCallbacks: public BLEServerCallbacks {
    void onConnect(BLEServer* pServer) {
      deviceConnected = true;
      Serial.println("Device connected");
    }

    void onDisconnect(BLEServer* pServer) {
      deviceConnected = false;
      Serial.println("Device disconnected");
    }
};

// Remove DC offset and reduce noise
// void applyNoiseReduction(int16_t* samples, int16_t* output, int numSamples) {
//   // Calculate the average (DC offset)
//   int32_t sum = 0;
//   for (int i = 0; i < numSamples; i++) {
//     sum += samples[i];
//   }
//   int16_t dcOffset = sum / numSamples;
  
//   // Apply DC offset removal and noise gate
//   for (int i = 0; i < numSamples; i++) {
//     // Remove DC offset
//     output[i] = samples[i] - dcOffset;
    
//     // Apply noise gate
//     if (abs(output[i]) < noiseFloor) {
//       output[i] = 0;
//     }
//   }
  
//   // Update noise floor estimate (adapt to environment)
//   int16_t currentNoiseLevel = 0;
//   for (int i = 0; i < numSamples; i++) {
//     currentNoiseLevel += abs(output[i]);
//   }
//   currentNoiseLevel /= numSamples;
  
//   // Only adapt noise floor during quiet periods
//   if (currentNoiseLevel < noiseFloor * 2) {
//     noiseFloor = (1 - NOISE_ADAPT_RATE) * noiseFloor + NOISE_ADAPT_RATE * currentNoiseLevel;
//   }
// }
#define LP_FILTER_ALPHA 0.1     // 滤波系数，值越小滤波越强 (0.05-0.2适合beat检测)

// 滤波状态变量
static float lastFilteredSample = 0;

// 应用简化版低通滤波器
void applySimpleLowPassFilter(int16_t* input, int16_t* output, int numSamples) {
  for(int i = 0; i < numSamples; i++) {
    // 简单IIR滤波: y[n] = alpha*x[n] + (1-alpha)*y[n-1]
    float filtered = LP_FILTER_ALPHA * input[i] + (1.0 - LP_FILTER_ALPHA) * lastFilteredSample;
    lastFilteredSample = filtered;
    output[i] = (int16_t)filtered;
  }
}

// 改进的噪声消除函数，使用简化低通滤波器
void applyNoiseReduction(int16_t* samples, int16_t* output, int numSamples) {
  // 临时缓冲区用于低通滤波
  static int16_t filteredBuffer[BUFFER_SIZE];
  
  // 应用简化低通滤波器
  applySimpleLowPassFilter(samples, filteredBuffer, numSamples);
  
  // 计算平均值(DC偏移)
  int32_t sum = 0;
  for (int i = 0; i < numSamples; i++) {
    sum += filteredBuffer[i];
  }
  int16_t dcOffset = sum / numSamples;
  
  // 计算样本标准差以自动调整增益
  float sumSquares = 0;
  for (int i = 0; i < numSamples; i++) {
    int16_t centered = filteredBuffer[i] - dcOffset;
    sumSquares += centered * centered;
  }
  float stdDev = sqrt(sumSquares / numSamples);
  
  // 应用DC偏移移除、增益和噪声门限
  for (int i = 0; i < numSamples; i++) {
    // 移除DC偏移
    float sample = filteredBuffer[i] - dcOffset;
    // 应用软噪声门限(soft noise gate)而不是硬切
    if (abs(sample) < noiseFloor*1.2) {
      // 平滑噪声门限，而不是直接设为0
      float ratio = abs(sample) / noiseFloor;
      sample *= ratio * ratio;  // 平方关系使低于门限的信号平滑衰减
    }
    
    output[i] = (int16_t)sample;
  }
  
  // 更新噪声门限估计(适应环境)
  int16_t currentNoiseLevel = 0;
  for (int i = 0; i < numSamples; i++) {
    currentNoiseLevel += abs(output[i]);
  }
  currentNoiseLevel /= numSamples;
  
  // 仅在安静期间调整噪声门限
  if (currentNoiseLevel < noiseFloor * 2) {
    noiseFloor = (1 - NOISE_ADAPT_RATE) * noiseFloor + NOISE_ADAPT_RATE * currentNoiseLevel;
  }
}

// Detect beats using energy-based algorithm
bool detectBeat(int16_t* samples, int numSamples) {
  // Calculate signal energy (RMS)
  float energy = 0;
  for (int i = 0; i < numSamples; i++) {
    energy += (float)samples[i] * samples[i];
  }
  energy = sqrt(energy / numSamples);
  
  // Smooth the energy value
  currentEnergy = (1 - ENERGY_SMOOTHING) * currentEnergy + ENERGY_SMOOTHING * energy;
  
  // Store in circular buffer
  energyBuffer[energyIndex] = currentEnergy;
  energyIndex = (energyIndex + 1) % ENERGY_BUFFER_SIZE;
  
  // Calculate average energy
  float sum = 0;
  for (int i = 0; i < ENERGY_BUFFER_SIZE; i++) {
    sum += energyBuffer[i];
  }
  averageEnergy = sum / ENERGY_BUFFER_SIZE;
  
  // Check if enough time has passed since the last beat
  unsigned long currentTime = millis();
  if (currentTime - lastBeatTime < MIN_BEAT_INTERVAL) {
    return false;
  }
  
  // Beat detection logic
  if (currentEnergy > averageEnergy * BEAT_THRESHOLD && currentEnergy > noiseFloor * 3) {
    lastBeatTime = currentTime;
    beatIndicatorTime = currentTime;
    
    // Calculate beat strength (normalized)
    beatStrength = constrain((currentEnergy - averageEnergy) / averageEnergy, 0.0, 1.0);
    
    return true;
  }
  
  return false;
}

// Send beat data to client
void sendBeatData(float strength) {
  if (!deviceConnected) return;
  
  // Create a structured message: [flag byte, strength float (4 bytes)]
  messageData[0] = 0x01; // Beat indicator flag
  
  // Convert float to bytes
  memcpy(&messageData[1], &strength, sizeof(float));
  
  // Send the data
  pCharacteristic->setValue(messageData, 5); // 1 flag byte + 4 bytes float
  pCharacteristic->notify();
  
  Serial.print("Beat detected! Strength: ");
  Serial.println(strength);
}

void setup() {
  // Initialize serial
  Serial.begin(115200);
  while (!Serial) {
    ; // wait for serial port to connect
  }
  Serial.println("ESP32 PDM Beat Detection Server");

  // Setup I2S for PDM microphone
  I2S.setPinsPdmRx(PDM_CLOCK_PIN, PDM_DATA_PIN);
  
  if (!I2S.begin(I2S_MODE_PDM_RX, SAMPLE_RATE, I2S_DATA_BIT_WIDTH_16BIT, I2S_SLOT_MODE_MONO)) {
    Serial.println("Failed to initialize I2S!");
    while (1); // do nothing
  }
  
  Serial.println("I2S PDM initialized");
  
  // Initialize energy buffer
  for (int i = 0; i < ENERGY_BUFFER_SIZE; i++) {
    energyBuffer[i] = 0.0;
  }
  
  // Initialize message data
  memset(messageData, 0, MESSAGE_SIZE);
  
  // Initialize BLE
  BLEDevice::init("ESP32_Beat_Server");
  
  // Create the BLE Server
  pServer = BLEDevice::createServer();
  pServer->setCallbacks(new MyServerCallbacks());
  
  // Create the BLE Service
  BLEService *pService = pServer->createService(SERVICE_UUID);
  
  // Create a BLE Characteristic
  pCharacteristic = pService->createCharacteristic(
                      CHARACTERISTIC_UUID,
                      BLECharacteristic::PROPERTY_READ   |
                      BLECharacteristic::PROPERTY_WRITE  |
                      BLECharacteristic::PROPERTY_NOTIFY |
                      BLECharacteristic::PROPERTY_INDICATE
                    );
  
  // Create a BLE Descriptor
  pCharacteristic->addDescriptor(new BLE2902());
  
  // Start the service
  pService->start();
  
  // Start advertising
  BLEAdvertising *pAdvertising = BLEDevice::getAdvertising();
  pAdvertising->addServiceUUID(SERVICE_UUID);
  pAdvertising->setScanResponse(true);
  pAdvertising->setMinPreferred(0x06);
  pAdvertising->setMinPreferred(0x12);
  BLEDevice::startAdvertising();
  
  Serial.println("BLE server ready, waiting for connections...");
}

void loop() {
  // Read samples from I2S
  int sample = I2S.read();
  
  if (sample && sample != -1 && sample != 1) {
    // Add sample to buffer
    sampleBuffer[bufferIndex++] = (int16_t)sample;
    
    // When buffer is full, process it
    if (bufferIndex >= BUFFER_SIZE) {
      // Apply noise reduction
      applyNoiseReduction(sampleBuffer, processedBuffer, BUFFER_SIZE);
      
      // Detect beats
      beatDetected = detectBeat(processedBuffer, BUFFER_SIZE);
      
      if (beatDetected && deviceConnected) {
        // Send beat data to client
        sendBeatData(beatStrength);
      }
      
      // If connected, optionally send a downsampled version of the audio
      if (deviceConnected) {
        // Send compressed representation of the signal
        // This reduces the BLE data rate while still providing information about the signal
        
        // Send just 10 representative samples (every 50th sample)
        for (int i = 0; i < 10; i++) {
          int idx = i * 50;
          if (idx < BUFFER_SIZE) {
            int16_t value = processedBuffer[idx];
            pCharacteristic->setValue((uint8_t*)&value, sizeof(int16_t));
            pCharacteristic->notify();
            delay(5); // Small delay to avoid overwhelming the BLE stack
          }
        }
      }
      
      // Reset buffer index
      bufferIndex = 0;
    }
  }
  
  // Handle BLE connection status changes
  if (!deviceConnected && oldDeviceConnected) {
    delay(500); // Give the bluetooth stack time to get ready
    pServer->startAdvertising(); // Restart advertising
    Serial.println("Started advertising again");
    oldDeviceConnected = deviceConnected;
  }
  
  if (deviceConnected && !oldDeviceConnected) {
    oldDeviceConnected = deviceConnected;
  }
}

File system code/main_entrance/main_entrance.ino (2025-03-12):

#include <Arduino.h>
#include "display_manager.h"
#include "waveform_generator.h"
#include "button_handler.h"
#include "bluetooth_manager.h"
#include "stepper_motor.h"

// Update timing parameters - DECREASED for faster updates
unsigned long lastUpdateTime = 0;
const int updateInterval = 20;  // Update interval (ms) - DECREASED from 50ms to 20ms

#define RED_LED_PIN A10  
#define GREEN_LED_PIN A9  
#define GREEN_LED_BRIGHTNESS 32 
// BPM calculation
float currentBPM = 90.0;  // Default BPM
const float MIN_BPM = 40.0;  // Minimum allowed BPM
const float MAX_BPM = 220.0; // Maximum allowed BPM
const float DEFAULT_INTERNAL_BPM = 120.0; // Default BPM for internal source

// BPM calculation variables
const int BPM_BUFFER_SIZE = 5;  // Size of buffer for averaging BPM values
float bpmBuffer[BPM_BUFFER_SIZE]; // Buffer to store recent BPM values
int bpmBufferIndex = 0;  // Current index in the buffer
bool bpmBufferFilled = false;  // Flag to indicate if buffer is filled
unsigned long lastBpmUpdateTime = 0;
const int bpmUpdateInterval = 250;  // Update BPM every 250ms to avoid excessive calculation

// Function to display data source change notification
void displayDataSourceChangeNotification(DataSource source) {
  // Display notification on both screens
  display1.clearDisplay();
  display1.setTextSize(1);
  display1.setTextColor(SSD1306_WHITE);
  display1.setCursor(0, 0);
  display1.println(F("Data source changed to:"));
  display1.setTextSize(2);
  display1.setCursor(10, 20);
  display1.println(source == SOURCE_INTERNAL ? F("INTERNAL") : F("BLUETOOTH"));
  display1.display();
  
  display2.clearDisplay();
  display2.setTextSize(1);
  display2.setTextColor(SSD1306_WHITE);
  display2.setCursor(0, 0);
  display2.println(F("New data source:"));
  display2.setTextSize(2);
  display2.setCursor(10, 20);
  display2.println(source == SOURCE_INTERNAL ? F("INTERNAL") : F("BLUETOOTH"));
  display2.display();
  
  // When switching to internal source, reset BPM to default
  if (source == SOURCE_INTERNAL) {
    currentBPM = DEFAULT_INTERNAL_BPM;
    Serial.print("Switched to internal source, BPM set to: ");
    Serial.println(currentBPM);
    
    // Reset BPM buffer with the default value
    for (int i = 0; i < BPM_BUFFER_SIZE; i++) {
      bpmBuffer[i] = currentBPM;
    }
  }
  
  // Show for 2 seconds
  delay(2000);
}

// Calculate BPM from Bluetooth data
// For a real BPM calculation:
// float calculateBPM() {
//   // Time interval for measuring beats (in milliseconds)
//   const unsigned long measurementWindow = 5000; // 5 seconds sliding window
  
//   // Store timestamps of detected beats
//   static const int MAX_BEATS = 30;
//   static unsigned long beatTimes[MAX_BEATS];
//   static int beatCount = 0;
//   static int oldestBeatIndex = 0;
  
//   // Current time
//   unsigned long currentTime = millis();
  
//   // Record this beat time and increment count
//   beatTimes[oldestBeatIndex] = currentTime;
//   oldestBeatIndex = (oldestBeatIndex + 1) % MAX_BEATS;
//   if (beatCount < MAX_BEATS) beatCount++;
  
//   // Calculate BPM based on recorded beats
//   if (beatCount < 2) return MIN_BPM; // Need at least 2 beats
  
//   // Find oldest beat that's within our measurement window
//   int validBeatCount = 0;
//   int oldestValidBeat = oldestBeatIndex;
  
//   for (int i = 0; i < beatCount; i++) {
//     int index = (oldestBeatIndex - i + MAX_BEATS) % MAX_BEATS;
//     if (currentTime - beatTimes[index] <= measurementWindow) {
//       validBeatCount++;
//       oldestValidBeat = index;
//     } else {
//       break; // Found an old beat outside our window
//     }
//   }
  
//   if (validBeatCount < 2) return MIN_BPM; // Need at least 2 valid beats
  
//   // Calculate time span between oldest valid beat and now
//   unsigned long timeSpan = currentTime - beatTimes[oldestValidBeat];
  
//   // Convert to BPM: (beats-1) / timeSpan in minutes
//   // We use beats-1 because we're measuring intervals between beats
//   float bpm = (validBeatCount - 1) * 60000.0 / timeSpan;
  
//   // Constrain to valid range
//   if (bpm < MIN_BPM) bpm = MIN_BPM;
//   if (bpm > MAX_BPM) bpm = MAX_BPM;
  
//   return bpm;
// }

void setup() {
  Serial.begin(115200);
  Serial.println("Starting ESP32 Waveform Display & Metronome...");
  
  // Initialize LED pins
  pinMode(RED_LED_PIN, OUTPUT);
  pinMode(GREEN_LED_PIN, OUTPUT);

  digitalWrite(RED_LED_PIN, LOW);
  digitalWrite(GREEN_LED_PIN, LOW);
  
  
  // Set initial state (off)
  ledcWrite(0, 0);
  
  // Initialize buffer with default BPM
  for (int i = 0; i < BPM_BUFFER_SIZE; i++) {
    bpmBuffer[i] = DEFAULT_INTERNAL_BPM;  // Start with internal default BPM
  }
  
  // Set initial BPM
  currentBPM = DEFAULT_INTERNAL_BPM;
  
  // Initialize button
  initButton();
  
  // Initialize displays
  if (!initDisplays()) {
    Serial.println("Display initialization failed");
    for(;;); // Infinite loop
  }
  
  // Display startup information
  displayStartupScreen();
  
  // Initialize waveform
  initWaveform();
  
  // Set waveform speed to a faster value (1-10 scale)
  setWaveformSpeed(5);  // Set to a middle value, can be adjusted
  
  // Initialize metronome
  initMetronome();
  
  // Initialize Bluetooth
  if (!initBluetooth()) {
    Serial.println("Bluetooth initialization failed");
    // Continue anyway, we can still use internal data source
  }
  
  // Wait 2 seconds before starting
  delay(2000);
  
  Serial.println("Starting waveform generation and metronome...");
}
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

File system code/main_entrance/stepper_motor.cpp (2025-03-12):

#include "stepper_motor.h"

// Stepper motor step sequence (full step mode)
const int stepSequence[4][4] = {
  { 1, 0, 1, 0 },  // Step 1
  { 0, 1, 1, 0 },  // Step 2
  { 0, 1, 0, 1 },  // Step 3
  { 1, 0, 0, 1 }   // Step 4
};

// Metronome configuration
const int STEPS_PER_REVOLUTION = 200;                        // Standard for most steppers (1.8° per step)
const int STEPS_FOR_180_DEGREES = STEPS_PER_REVOLUTION / 2;  // 100 steps
const int MAX_SWING_STEPS = STEPS_FOR_180_DEGREES / 2;       // 50 steps (90 degrees) to each side

// BPM thresholds for adjusting swing amplitude
const float BPM_THRESHOLD_1 = 120.0;  // Above this, reduce swing
const float BPM_THRESHOLD_2 = 160.0;  // Above this, reduce swing more
const float BPM_THRESHOLD_3 = 200.0;  // Above this, reduce swing even more

// Metronome state
static int currentStepPosition = 0;      // Current physical step position
static int targetStepPosition = 0;       // Target step position
static int currentDegreePosition = 0;    // Current position in degrees
static bool swingDirectionRight = true;  // Current swing direction
static unsigned long lastStepTime = 0;   // Last motor step time
static unsigned long lastBeatTime = 0;   // Last time we processed a beat
static bool beatStarted = false;         // Flag for beat starting
static int swingAmplitude = 90;          // Current swing amplitude (degrees to each side)
static bool motorEnabled = true;         // Flag to enable/disable motor
static int currentStepIndex = 0;         // Current step sequence index

// For timing calculations
static float currentBpm = DEFAULT_BPM;     // Current BPM
static unsigned long beatInterval = 1000;  // Interval between beats in ms (60 BPM default)

// Initialize metronome
void initMetronome() {
  // Set all motor control pins as outputs
  pinMode(COIL_A1, OUTPUT);
  pinMode(COIL_A2, OUTPUT);
  pinMode(COIL_B1, OUTPUT);
  pinMode(COIL_B2, OUTPUT);

  // Initialize all pins to LOW
  digitalWrite(COIL_A1, LOW);
  digitalWrite(COIL_A2, LOW);
  digitalWrite(COIL_B1, LOW);
  digitalWrite(COIL_B2, LOW);

  // Initialize timing
  currentBpm = DEFAULT_BPM;
  beatInterval = 60000 / currentBpm;  // milliseconds per beat
  swingAmplitude = 90;                // Default to full swing

  Serial.println("Stepper motor initialized");

  // Center the metronome
  centerMetronome();

  // Turn off motor coils to prevent overheating when not moving
  disableMotor();
}

// Enable motor coils
void enableMotor() {
  motorEnabled = true;
}

// Disable motor coils to prevent overheating
void disableMotor() {
  digitalWrite(COIL_A1, LOW);
  digitalWrite(COIL_A2, LOW);
  digitalWrite(COIL_B1, LOW);
  digitalWrite(COIL_B2, LOW);
  motorEnabled = false;
}

// Step the motor once in the specified direction
void stepMotor(bool clockwise) {
  // Enable motor if not enabled
  if (!motorEnabled) {
    enableMotor();
  }

  // Update step index based on direction
  if (clockwise) {
    currentStepIndex = (currentStepIndex + 1) % 4;
  } else {
    currentStepIndex = (currentStepIndex + 3) % 4;  // Same as -1 but stays positive
  }

  // Apply the step pattern to the motor pins
  digitalWrite(COIL_A1, stepSequence[currentStepIndex][0]);
  digitalWrite(COIL_A2, stepSequence[currentStepIndex][1]);
  digitalWrite(COIL_B1, stepSequence[currentStepIndex][2]);
  digitalWrite(COIL_B2, stepSequence[currentStepIndex][3]);

  // Update current position
  if (clockwise) {
    currentStepPosition++;
  } else {
    currentStepPosition--;
  }
}

// Convert from degrees to motor steps
int degreesToSteps(int degrees) {
  // Simple conversion from degrees to steps
  return (degrees * STEPS_PER_REVOLUTION) / 360;
}

// Center the metronome
void centerMetronome() {
  Serial.println("Centering metronome...");

  // Enable motor
  enableMotor();

  // First, do a reset sequence to ensure motor is responsive
  // Move a small amount in each direction
  for (int i = 0; i < 20; i++) {
    stepMotor(true);
    delay(5);
  }

  for (int i = 0; i < 20; i++) {
    stepMotor(false);
    delay(5);
  }

  // Reset position counters
  currentStepPosition = 0;
  targetStepPosition = 0;
  currentDegreePosition = 0;
  swingDirectionRight = true;

  Serial.println("Metronome centered");

  // Turn off motor coils to prevent overheating
  disableMotor();
}

// Set BPM with constraints
void setBPM(float bpm) {
  // Constrain BPM to valid range
  bpm = constrain(bpm, StepperMotor::MIN_BPM, StepperMotor::MAX_BPM);

  // Only update if there's a meaningful change
  if (abs(bpm - currentBpm) > 1.0) {
    currentBpm = bpm;
    beatInterval = 60000 / currentBpm;  // milliseconds per beat

    // Adjust swing amplitude based on BPM
    if (currentBpm > BPM_THRESHOLD_3) {
      swingAmplitude = 60;  // At very high BPM, smaller swing
    } else if (currentBpm > BPM_THRESHOLD_2) {
      swingAmplitude = 90;  // At high BPM, reduced swing
    } else if (currentBpm > BPM_THRESHOLD_1) {
      swingAmplitude = 120;  // At medium-high BPM, moderate swing
    } else {
      swingAmplitude = 150;  // At normal BPM, full swing
    }

    Serial.print("BPM updated to: ");
    Serial.print(currentBpm);
    Serial.print(", Swing amplitude: ±");
    Serial.print(swingAmplitude);
    Serial.println("°");
  }
}
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

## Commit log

2025-01-28 update: pcb
    [514_pcb.kicad_pcb, 514_pcb.kicad_sch]
2025-02-13 update power spreadsheet
    [Power Model Spreadsheet.xlsx]
2025-02-13 update spread sheet
    [Power Model Spreadsheet.xlsx]
2025-03-03 display update
    [514_display-B_Cu.gbr, 514_display-B_Mask.gbr, 514_display-B_Paste.gbr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]
2025-03-04 update 3d print files
    [514_display upup.stl, 514_display v1.stl, 514_display.kicad_pcb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]
2025-03-09 update arduino test codes
